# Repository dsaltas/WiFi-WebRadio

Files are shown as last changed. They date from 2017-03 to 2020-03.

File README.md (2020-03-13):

## WiFi WebRadio

This is a hardware project for [Ka-Radio](https://github.com/karawin/Ka-Radio).

It is based on [ESP8266](https://espressif.com/en/products/hardware/esp8266ex/overview) 
chip and audio codec [VS1053b](http://www.vlsi.fi/en/products/vs1053.html) chip.

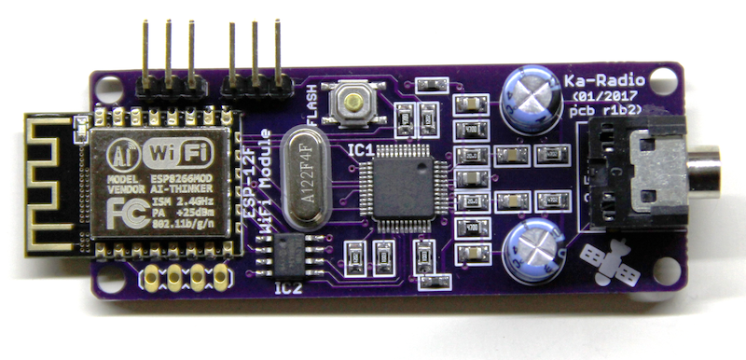
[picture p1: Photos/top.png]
Top

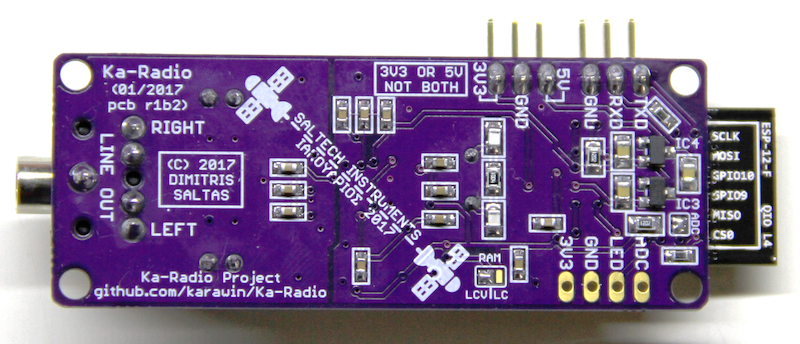
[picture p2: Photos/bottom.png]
Bottom


### Features

- You can power it with 3V3 **or** 5V. Do **NOT** use both power inputs at the same time.

- You can connect an external [keypad](https://github.com/karawin/Ka-Radio/blob/master/Hardware/controles.pdf) for control. Just unsolder the ADC jumper.

- <del>The RXD pin is 5V tolerant so you can connect a 5V microcontroller</del>.
  <br>It's official! ESP8266 I/Os are 5V tolerant.

- Output is line-out with large audio grade electrolytic capacitors. Safe to connect an external amplifier.

- You can use two types of SRAM. 23LCV1024 **or** 23LC1024. Just solder the proper jumper.

Tested and working as expected.

You can order the pcb from [OSH Park](https://oshpark.com/shared_projects/Byku3T3d).

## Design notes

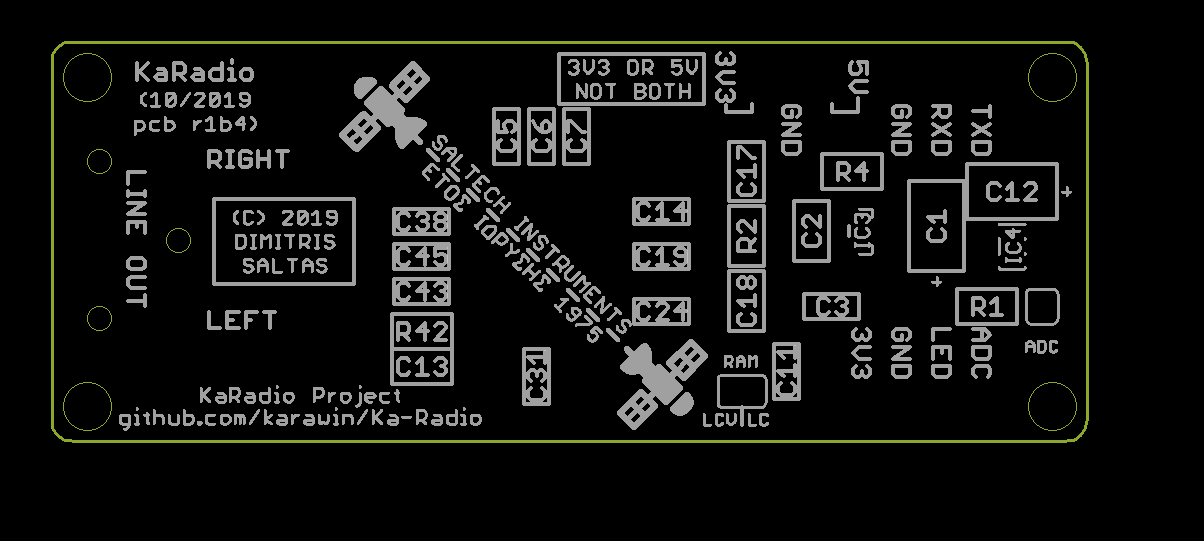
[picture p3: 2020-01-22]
Hardware/Reference designators (bottom).png

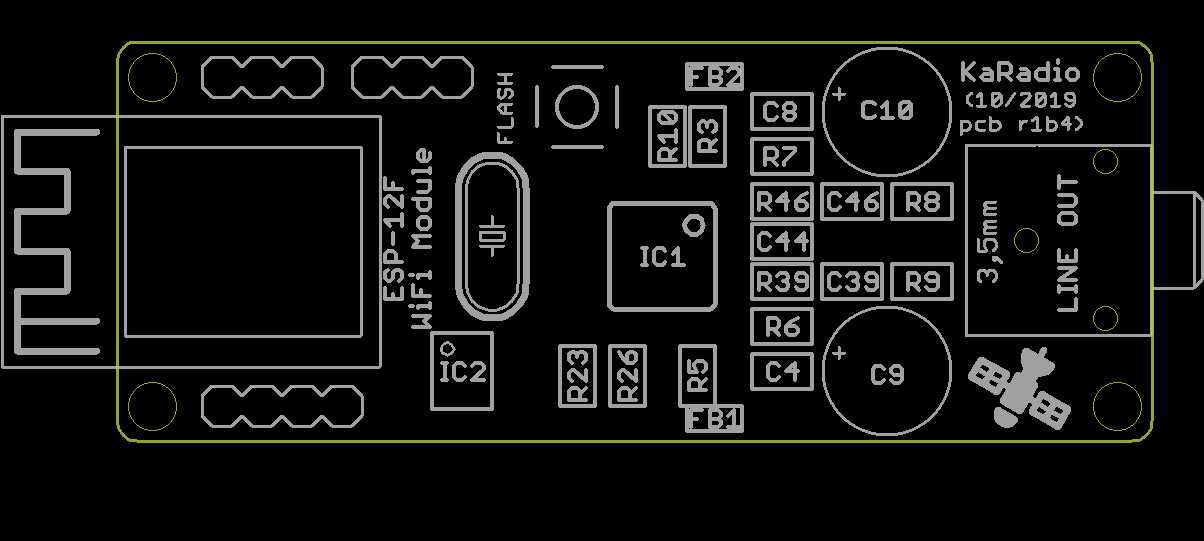
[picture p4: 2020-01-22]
Hardware/Reference designators (top).png

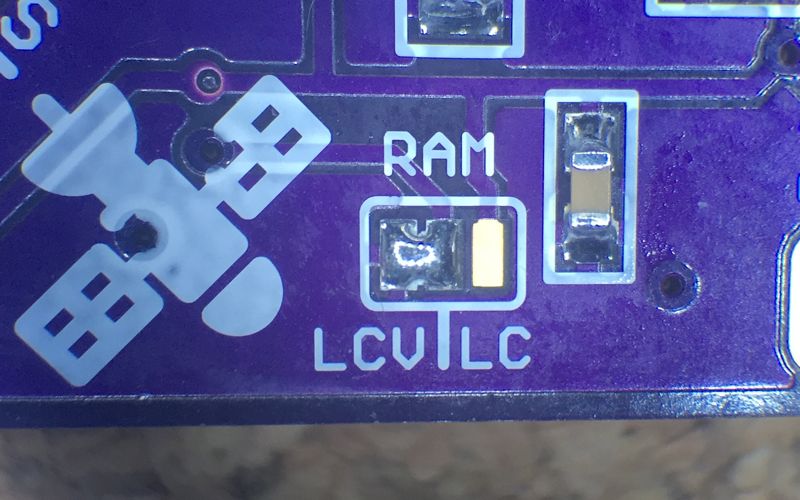
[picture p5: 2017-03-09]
Photos/lcv.png

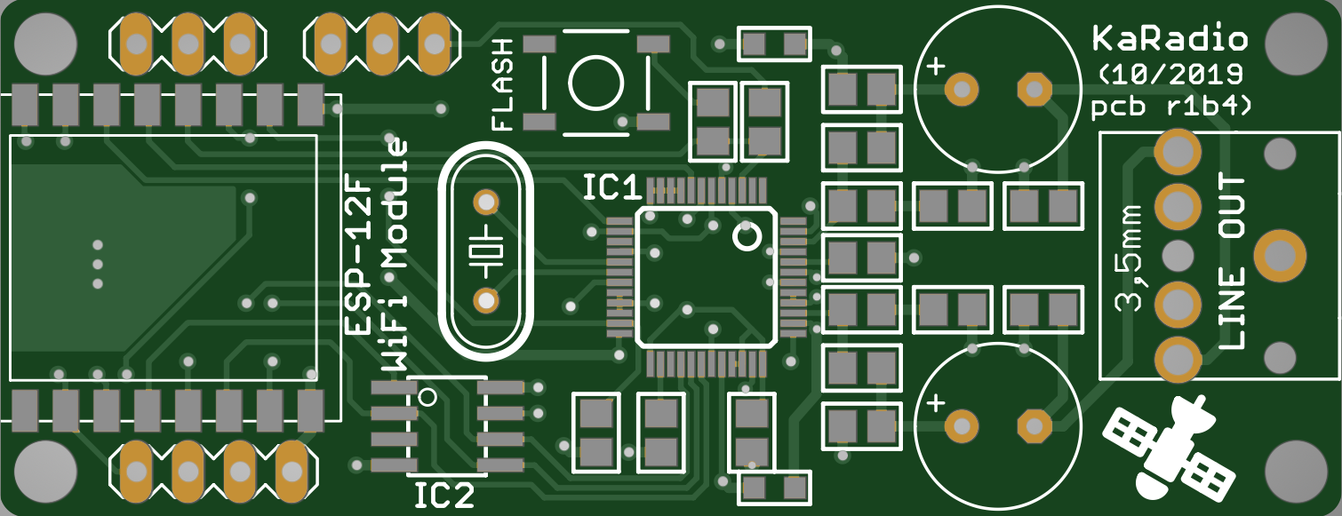
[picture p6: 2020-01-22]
Doc/top_rendered.png

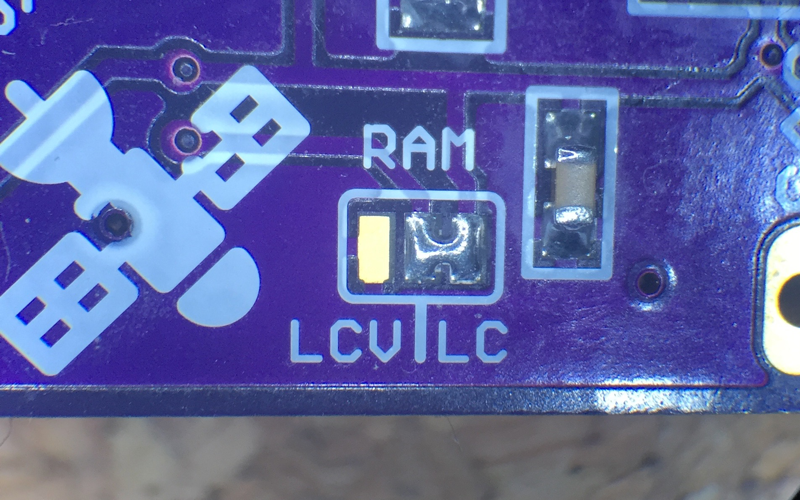
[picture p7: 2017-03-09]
Photos/lc.png

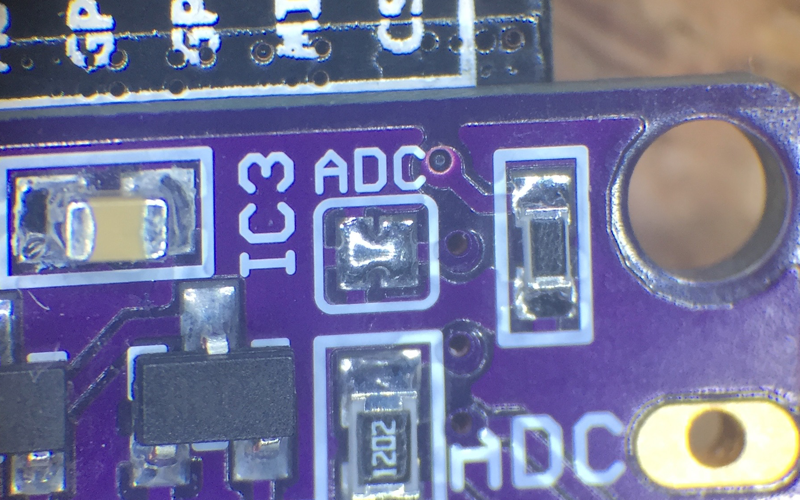
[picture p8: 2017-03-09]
Photos/adc.png

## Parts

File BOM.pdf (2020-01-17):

## WiFi WebRadio BOM (r1B4, 2020-17-01) Project source at https://github.com/dsaltas/WiFi-WebRadio

Qty | Part name | Package | Reference Designator | Mouser | TME
4 | 12KΩ 1% | 0805 | R1, R3, R4, R23 | 667-ERJ-6ENF1202V
1 | 1MΩ 1% | 0805 | R2 | 667-ERJ-6ENF1004V
2 | 100KΩ 1% | 0805 | R5, R26 | 667-ERJ-6ENF1003V
3 | 470Ω 1% | 0805 | R6, R7, R10 | 667-ERJ-6ENF4700V
2 | 47ΚΩ 1% | 0805 | R8, R9 | 667-ERJ-6ENF4702V
2 | 20Ω 1% | 0805 | R39, R46 | 667-ERJ-6ENF20R0V
1 | 10Ω 1% | 0805 | R42 | 667-ERJ-6ENF10R0V
2 | 47µF 20% 10V | 1210 | C1, C12 | 667-10TPE47MAZB
1 | 10µF 10% 16V X5R | 0805 | C2 | 81-GRM21BR61C106KE15
12 | 0.1µF 10% 50V X7R | 0603 | C3, C5, C6, C7, C11, C14, C19, C24, C31, C38, C43, C45 | 80-C0603C104K5R
2 | 3300pF 10% 50V X7R | 0805 | C4, C8 | 80-C0805C332K5RAC
2 | 470µF 20% 16V | Radial | C9, C10 | 647-UKA1C471MPD
1 | 47nF 10% 50V X7R | 0805 | C13 | 581-08055C473K
2 | 22pF 5% 50V C0G | 0805 | C17, C18 | 80-C0805C220J5G
2 | 10nF 10% 50V X7R | 0805 | C39, C46 | 81-GRM40X103K50D
1 | 1µF 10% 16V X5R | 0805 | C44 | 81-GRM21R61C105KA01L
2 | Chip Ferrite Bead | 0603 | FB1, FB2 | 81-BLM18PG221SN1D
1 | VS1053b Audio Codec | LQFP48 | IC1 | 485-1681 | VS1053B-L
1 | SRAM 1024K | SOIC8 | IC2 | 579-23LCV1024-I/SN or 579-23LC1024-I/SN
1 | LDO 1V8 Regulator | SOT-23-3 | IC3 | 579-MCP1703AT1802ECB
1 | LDO 3V3 Regulator | SOT-23-5 | IC4 | 595-TLV75533PDBVR
1 | ESP-12F WiFi Module | | MD1
1 | 12.288MHz ±20ppm | HC-49/US | X1 | 815-ABL-12.288-B2
1 | Tactile Switch | SMD | S1 | 688-SKQGAD
1 | Audio Jack | Through Hole | K1 | 806-STX-3100-5N

1

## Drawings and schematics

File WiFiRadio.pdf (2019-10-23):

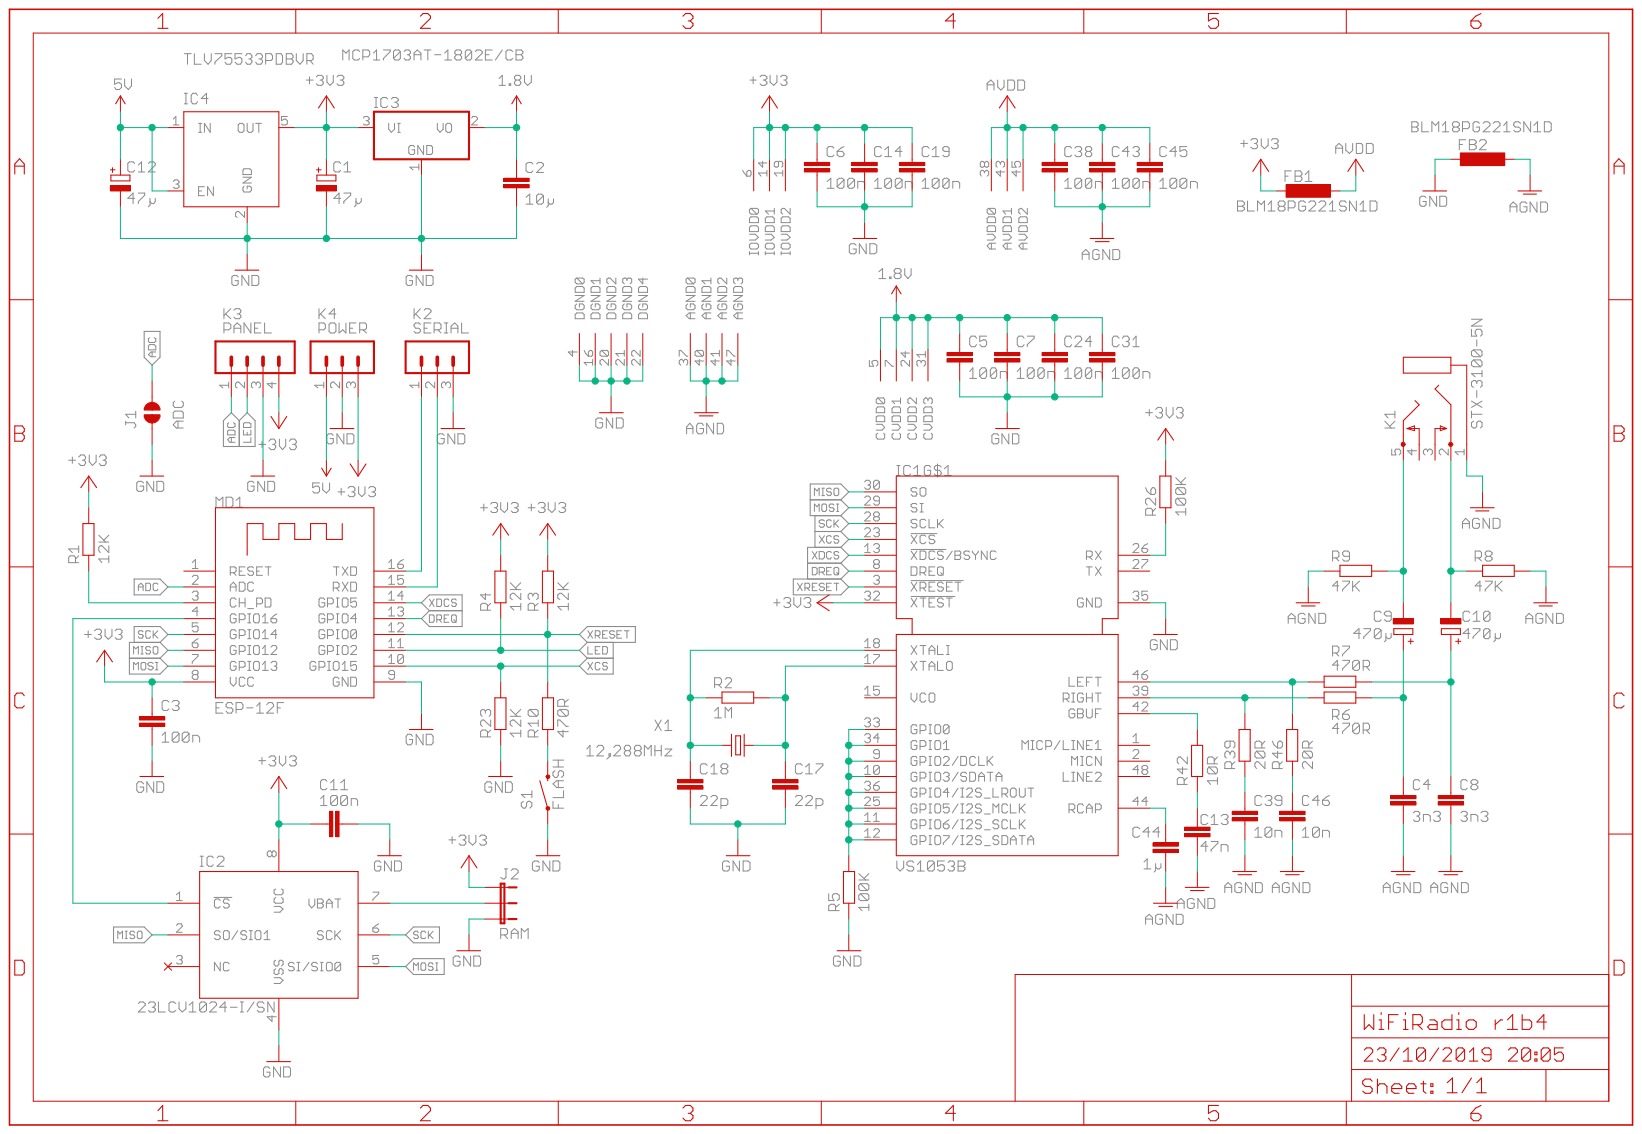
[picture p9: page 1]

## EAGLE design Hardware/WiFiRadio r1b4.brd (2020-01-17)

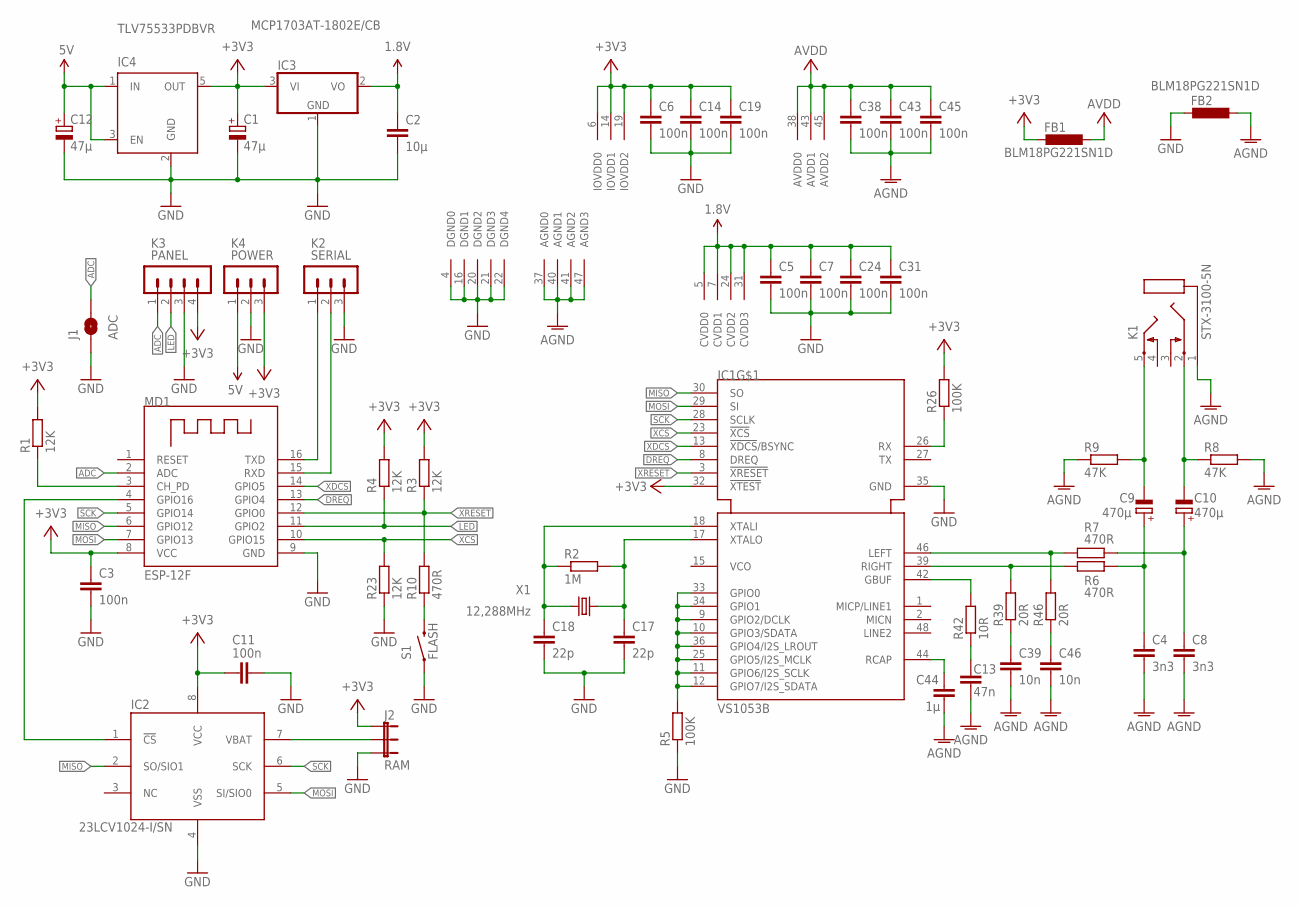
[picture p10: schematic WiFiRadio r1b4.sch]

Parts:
C1, C12: 47μ; SMC_B
C2: 10μ; C0805
C3, C5, C6, C7, C11, C14, C19, C24, C31, C38, C43, C45: 100n; C0603
C4, C8: 3n3; C0805
C9, C10: 470μ; E3,5-8
C13: 47n; C0805
C17, C18: 22p; C0805
C39, C46: 10n; C0805
C44: 1μ; C0805
FB1, FB2: BLM18PG221SN1D; L2012C
IC1: VS1053B; LQFP48
IC2: 23LCV1024-I/SN; SO-08
IC3: MCP1703AT-1802E/CB; SOT23
IC4: TLV75533PDBVR; SOT23-5
J1: ADC; SJ_2S
J2: RAM; SJ_3
K1: STX-3100-5N; STX3100
K2: SERIAL; MA03-1
K3: PANEL; MA04-1
K4: POWER; MA03-1
MD1: ESP-12F
R1, R3, R4, R23: 12K; R0805
R2: 1M; R0805
R5, R26: 100K; R0805
R6, R7, R10: 470R; R0805
R8, R9: 47K; R0805
R39, R46: 20R; R0805
R42: 10R; R0805
S1: FLASH; TACTILE-SWITCH-SMD
X1: 12,288MHz; HC49/S

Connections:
1.8V: C2.1, C5.1, C7.1, C24.1, C31.1, IC1.5 (CVDD0), IC1.7 (CVDD1), IC1.24 (CVDD2), IC1.31 (CVDD3), IC3.2 (VO)
5V: C12.+, IC4.1 (IN), IC4.3 (EN), K4.1
+3V3: C1.+, C3.1, C6.1, C11.1, C14.1, C19.1, FB1.2, IC1.6 (IOVDD0), IC1.14 (IOVDD1), IC1.19 (IOVDD2), IC1.32 (!XTEST), IC2.8 (VCC), IC3.3 (VI), IC4.5 (OUT), J2.1, K3.4, K4.3, MD1.8 (VCC), R1.2, R3.2, R4.2, R26.2
ADC: J1.2, K3.1, MD1.2 (ADC)
AGND: C4.2, C8.2, C13.2, C38.2, C39.2, C43.2, C44.2, C45.2, C46.2, FB2.1, IC1.37 (AGND0), IC1.40 (AGND1), IC1.41 (AGND2), IC1.47 (AGND3), K1.1, R8.2, R9.1
DREQ: IC1.8 (DREQ), MD1.13 (GPIO4)
GND: C1.-, C2.2, C3.2, C5.2, C6.2, C7.2, C11.2, C12.-, C14.2, C17.2, C18.2, C19.2, C24.2, C31.2, FB2.2, IC1.4 (DGND0), IC1.16 (DGND1), IC1.20 (DGND2), IC1.21 (DGND3), IC1.22 (DGND4), IC1.35 (GND), IC2.4 (VSS), IC3.1 (GND), IC4.2 (GND), J1.1, J2.3, K2.3, K3.3, K4.2, MD1.9 (GND), R5.1, R23.1, S1.1
GPIO: IC1.9 (GPIO2/DCLK), IC1.10 (GPIO3/SDATA), IC1.11 (GPIO6/I2S_SCLK), IC1.12 (GPIO7/I2S_SDATA), IC1.25 (GPIO5/I2S_MCLK), IC1.33 (GPIO0), IC1.34 (GPIO1), IC1.36 (GPIO4/I2S_LROUT), R5.2
LED: K3.2, MD1.11 (GPIO2), R4.1
LEFT: IC1.46 (LEFT), R7.1, R46.2
MISO: IC1.30 (SO), IC2.2 (SO/SIO1), MD1.6 (GPIO12)
MOSI: IC1.29 (SI), IC2.5 (SI/SIO0), MD1.7 (GPIO13)
unnamed: IC2.1 (!CS), MD1.4 (GPIO16)
unnamed: MD1.3 (CH_PD), R1.1
unnamed: C17.1, IC1.17 (XTALO), R2.2, X1.1
unnamed: C18.1, IC1.18 (XTALI), R2.1, X1.2
unnamed: IC1.42 (GBUF), R42.2
unnamed: C4.1, C9.+, R6.2
unnamed: C8.1, C10.+, R7.2
unnamed: IC2.7 (VBAT), J2.2
unnamed: C39.1, R39.1
unnamed: C46.1, R46.1
unnamed: C13.1, R42.1
unnamed: C9.-, K1.5, R9.2
unnamed: C10.-, K1.2, R8.1
unnamed: R10.1, S1.3 (2)
RCAP: C44.1, IC1.44 (RCAP)
RIGHT: IC1.39 (RIGHT), R6.1, R39.2
RX: IC1.26 (RX), R26.1
RXD: K2.2, MD1.15 (RXD)
SCK: IC1.28 (SCLK), IC2.6 (SCK), MD1.5 (GPIO14)
TXD: K2.1, MD1.16 (TXD)
V+: C38.1, C43.1, C45.1, FB1.1, IC1.38 (AVDD0), IC1.43 (AVDD1), IC1.45 (AVDD2)
XCS: IC1.23 (!XCS), MD1.10 (GPIO15), R23.2
XDCS: IC1.13 (!XDCS!/BSYNC), MD1.14 (GPIO5)
XRESET: IC1.3 (!XRESET), MD1.12 (GPIO0), R3.1, R10.2

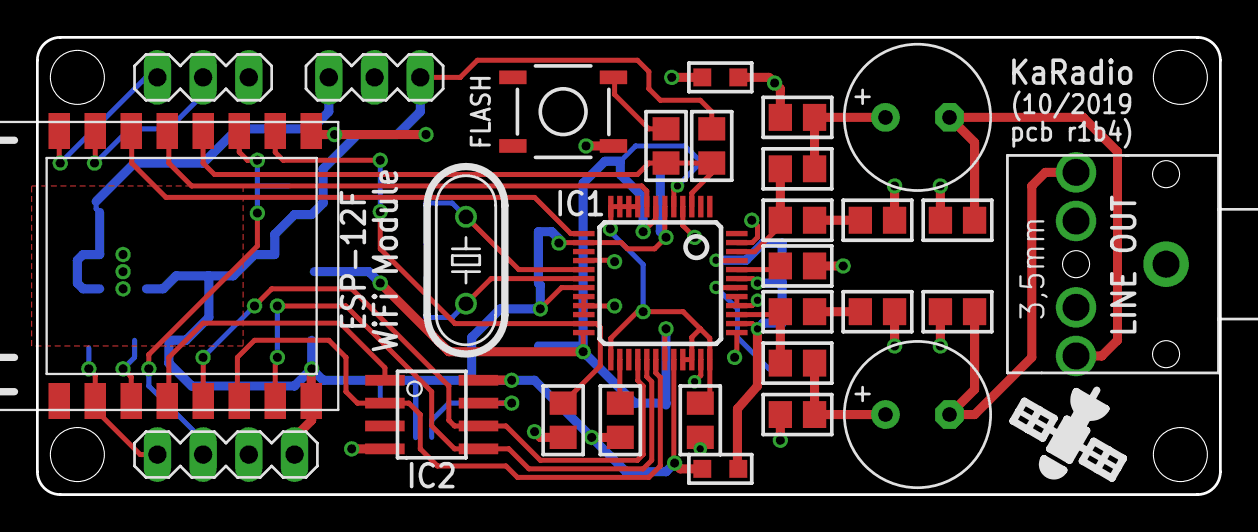
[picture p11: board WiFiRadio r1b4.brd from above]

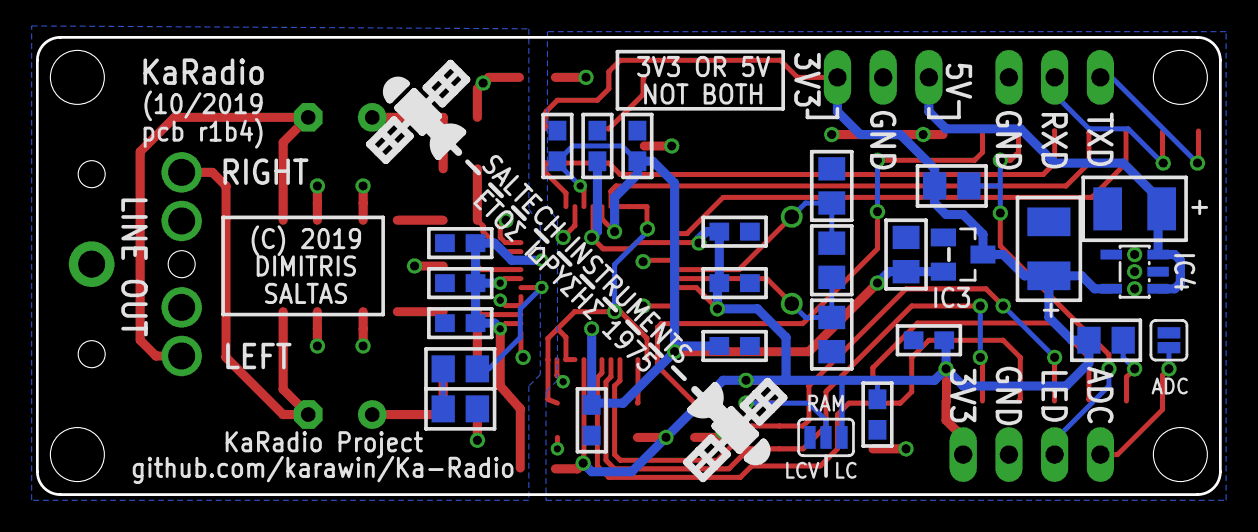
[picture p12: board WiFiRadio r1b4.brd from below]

Board: 2 copper layers, 65.7 x 25.4 mm, 55 parts (26 on the bottom side), 36 nets.

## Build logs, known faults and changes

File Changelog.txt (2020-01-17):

2019-10-23 Dimitris Saltas <saltech1975@gmail.com>

* IC4 (3.3V Regulator) changed from SOT23-3 to SOT23-5.

* C1, C12 capacitors changed from 0805 to 1210.

* C9, C10 capacitors changed from 220uF to 470uF.

* R42, C13 added this RC-combo to GBUF output pin.

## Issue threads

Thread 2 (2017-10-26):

Drawings with Schamatic reference designators

gvoigtlaender, 2017-10-26:
Could you provide a rendered drawing including the referenced parts of Schamatic (e.g. R5, C8, ...)? I got my pcbs from OSH Park + lots of SMDs, but it is hard to pick correct parts with Schematic only

Thanks

dsaltas, 2017-10-28:
Hello gvoigtlaender,

Thank you for your interest. You can download EAGLE (https://www.autodesk.com/products/eagle/free-download) and open the file WiFiRadio.brd (under Hardware folder). You will find all the reference designators there. Good luck with your build!

dsaltas, 2018-01-03:
Added in hardware folder.

gvoigtlaender, 2018-01-04:
Thank you very much

Closed 2018-01-03.

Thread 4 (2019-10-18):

Change MCP1703-3.3 to something more powerful

enjoyneering, 2019-10-18:
Hi, dsaltas

According to this studies: [ESP8266 killing itself](https://www.ondrovo.com/a/20170205-esp-self-destruct/) & [Determining the ESP8266 power consumption](https://www.ondrovo.com/a/20170207-esp-consumption/). The ESP8266 uses about 70 mA with frequent short surges (1 μs at 400 mA). In addition, during startup, it draws 430 mA for 40 ms. The MCP1703-3.3 can provide only 250mA. This is what happens on the 3.3V rail on your board.

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

Huge 10Hz peaks around 600 mV if you use the XC6206-3.3. Same story with MCP1703-3.3, but peaks are two times smaller. Ka-Radio is unstable. Small 10uF x 6.3v tantalum capacitor drop emissions to 150mV & 40mV.  WeMos Mini has ME6211 LDO in SOT23-**5** and has peaks of about 40mV with an additional 10uF tantalum capacitor.

Can you change the reference design to accept 47uF tantalum capacitors & 500mA SOT23-**5** LDOs, such as ME6211, RT9193 or RT9013?

I've used XC6206-1.8 for 1.8v rail. It is cheap, easy to find on eBay & it works fine. Would be nice if you add it to the BOM as a replacement option.

Thank you.

dsaltas, 2019-10-18:
Hi,
Thanks for your feedback,

I have never experienced any power issues and instabilities with the Ka-Radios I have build and tested, although I mostly feed them with 3,3V as the ESP8266 is a 3,3V device.

I will definitely take a look if I can change the footprint of 3,3V LDO to SOT23-5 package as there are many 500mA capable LDOs out there such as MIC5219 or your recommendations.
I will also try to change footprint of filtering capacitor to 1210 package like this 10TPE47MAZB.
It is 47uF/10V tantalum.

In the meantime you can use an ME6211 as it comes in SOT23-3 package. It's a direct drop-in replacement.

Best regards.

enjoyneering, 2019-10-18:
Hi, dsaltas

The ME6211 in SOT23-3 package is hard to find on Ebay and Aliexpress. Looking forward to changes and thank you for the awesome board.

enjoyneering, 2019-10-18:
Forgot to mention, the [VS10XX AppNote: Connecting analog outputs](http://www.vlsi.fi/fileadmin/app_notes/vs10XXan_output.pdf) is suggesting to add RC-combo to GBUF pin even if you don't use GBUF as output. It is protecting GBUF pin from static electricity.

dsaltas, 2019-10-18:
Hi,
I have already added this RC-combo to GBUF output pin in a newer revision board (r1b3) that build for myself. I never uploaded the newer revision, mostly because I removed the resistors divider from RXD pin. I am using 3,3V so I didn't need the 5V tolerance. I had also increased the values of the output capacitors for better bass response. Apart from these changes, both boards are pretty much the same. You can find the newer revision on hardware directory.

enjoyneering, 2019-10-18:
ESP8266 unofficially 5v tolerant. The CEO of Espressif Systems confirmed it in the tweeter. I've connected many times 5v I2C to GPIO4 & GPIO5.

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

Calculation of output capacitor sizes is given on page 8 .I changed mine to 100 microfarads, this is more than enough for 10Kohm amplifier input (do not plan to use it with headphones).

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

Closed 2019-10-31.

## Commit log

2017-03-07 EAGLE Schematic
    [WiFiRadio.sch]
2017-03-07 EAGLE Board
2017-03-07 Schematic in PDF
2017-03-09 Bill of materials
2017-08-26 Gerber files added.
2019-10-23 Schematics in PDF
2020-01-17 Add BOM
2020-01-17 Replace BOM

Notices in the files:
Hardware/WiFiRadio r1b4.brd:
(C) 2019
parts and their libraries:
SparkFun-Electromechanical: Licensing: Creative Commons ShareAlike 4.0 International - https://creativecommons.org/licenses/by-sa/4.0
